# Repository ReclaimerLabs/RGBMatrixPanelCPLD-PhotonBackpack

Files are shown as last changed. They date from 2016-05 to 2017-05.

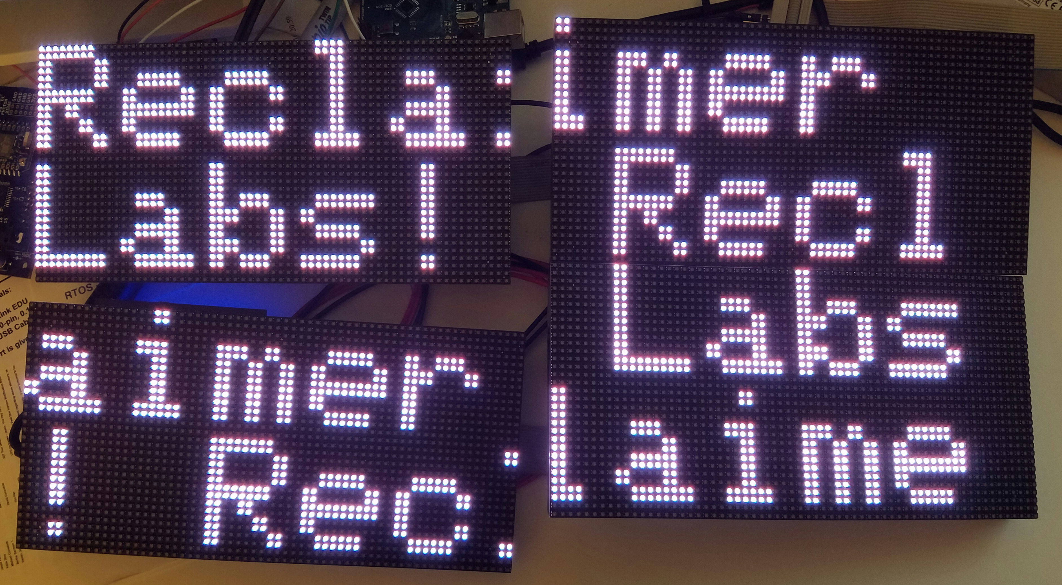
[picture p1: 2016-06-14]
documentation/panel_prototype.jpg

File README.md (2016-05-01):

Copyright (c) 2016 Jason Cerundolo

Permission is hereby granted, free of charge, to any person obtaining a copy
of this software and associated documentation files (the "Software"), to deal
in the Software without restriction, including without limitation the rights
to use, copy, modify, merge, publish, distribute, sublicense, and/or sell
copies of the Software, and to permit persons to whom the Software is
furnished to do so, subject to the following conditions:

The above copyright notice and this permission notice shall be included in all
copies or substantial portions of the Software.

THE SOFTWARE IS PROVIDED "AS IS", WITHOUT WARRANTY OF ANY KIND, EXPRESS OR
IMPLIED, INCLUDING BUT NOT LIMITED TO THE WARRANTIES OF MERCHANTABILITY,
FITNESS FOR A PARTICULAR PURPOSE AND NONINFRINGEMENT. IN NO EVENT SHALL THE
AUTHORS OR COPYRIGHT HOLDERS BE LIABLE FOR ANY CLAIM, DAMAGES OR OTHER
LIABILITY, WHETHER IN AN ACTION OF CONTRACT, TORT OR OTHERWISE, ARISING FROM,
OUT OF OR IN CONNECTION WITH THE SOFTWARE OR THE USE OR OTHER DEALINGS IN THE
SOFTWARE.

RGB Matrix Panel CPLD Photon Backpack
==================

An interface board between a Particle Photon and an RGB Matrix Panel. 
A CPLD provides the interface between the two and handles protocol 
conversion. 

Pick up an RGB LED panel from Adafruit. 
https://www.adafruit.com/products/2026

Pick up a CPLD backpack from Reclaimer Labs. 
http://reclaimerlabs.com

Use with the matching Particle library. 
https://github.com/ReclaimerLabs/RGBmatrixpanelCPLD

This board allows the use of hardware timers and DMA to achieve low 
overhead transfers of information to the matrix panels. The CPLD on the 
backpack converts SPI data into the parallel format expected by 
the matrix panel. The only ongoing computation needed from the CPU 
is to set up the next DMA transfer and compute the time to display 
the next row of bit data. This take the CPU time needed from ~40% 
to <1% for two 32x32 panels. The limited factor is now RAM and 
transfer speed.

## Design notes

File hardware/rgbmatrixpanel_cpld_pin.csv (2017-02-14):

ispLEVER Classic 2.0.00.17.20.15 Fitter Report File
Project Name | rgbmatrixpanel_cpld
Project Path | D:\Projects\RGBMatrixPanelCPLD-PhotonBackpack\hardware
Project Fitted on | Sun Feb 05 16:48:18 2017
Pin | Pin_Type | Bank | GLB_Pad | Assigned | I/O_Type | Signal_Type | Signal_Name
1 | TDI | -
2 | I_O | 0 | A5
3 | I_O | 0 | A6
4 | I_O | 0 | A7
5 | GNDIO0 | -
6 | VCCIO0 | -
7 | I_O | 0 | A8
8 | I_O | 0 | A9
9 | I_O | 0 | A10
10 | TCK | -
11 | VCC | -
12 | GND | -
13 | I_O | 0 | A12
14 | I_O | 0 | A13
15 | I_O | 0 | A14
16 | I_O | 0 | A15 | * | LVCMOS18 | Output | clk_out
17 | INCLK2 | 1
18 | I_O | 1 | B0 | * | LVCMOS18 | Output | latch_out
19 | I_O | 1 | B1 | * | LVCMOS18 | Output | row_2_
20 | I_O | 1 | B2 | * | LVCMOS18 | Output | row_3_
21 | I_O | 1 | B3 | * | LVCMOS18 | Output | row_0_
22 | I_O | 1 | B4 | * | LVCMOS18 | Output | row_1_
23 | TMS | -
24 | I_O | 1 | B5 | * | LVCMOS18 | Output | rgbs_0_
25 | I_O | 1 | B6 | * | LVCMOS18 | Output | rgbs_2_
26 | I_O | 1 | B7 | * | LVCMOS18 | Output | rgbs_1_
27 | GNDIO1 | -
28 | VCCIO1 | -
29 | I_O | 1 | B8 | * | LVCMOS18 | Output | rgbs_3_
30 | I_O | 1 | B9 | * | LVCMOS18 | Output | rgbs_5_
31 | I_O | 1 | B10 | * | LVCMOS18 | Output | rgbs_4_
32 | TDO | -
33 | VCC | -
34 | GND | -
35 | I_O | 1 | B12
36 | I_O | 1 | B13 | * | LVCMOS18 | Input | reset
37 | I_O | 1 | B14 | * | LVCMOS18 | Input | clk
38 | I_O/OE | 1 | B15
39 | INCLK0 | 0 |  | * | LVCMOS18 | Input | si
40 | I_O/OE | 0 | A0 |  | LVCMOS18 | Output | rgbs_7_
41 | I_O | 0 | A1
42 | I_O | 0 | A2 |  | LVCMOS18 | Output | rgbs_6_
43 | I_O | 0 | A3
44 | I_O | 0 | A4

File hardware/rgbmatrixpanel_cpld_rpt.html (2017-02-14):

 ispLEVER Classic 2.0.00.17.20.15 Fitter Report File

Copyright(C), 1992-2012, Lattice Semiconductor Corporation

All Rights Reserved

The Basic/Detailed Report Format can be selected in the dialog box
Tools->Fitter Report File Format...

Project_Summary

Project Name         :  rgbmatrixpanel_cpld
Project Path         :  D:\Projects\RGBMatrixPanelCPLD-PhotonBackpack\hardware
Project Fitted on    :  Sun Feb 05 16:48:18 2017

Device               :  M4032_30
Package              :  44
GLB Input Mux Size   :  6
Available Blocks     :  2
Speed                :  -7.5
Part Number          :  LC4032V-75T44C
Source Format        :  Pure_Verilog_HDL

Project 'rgbmatrixpanel_cpld' Fit Successfully!

Compilation_Times

Prefit Time                     0 secs
Load Design Time                0.01 secs
Partition Time                  0.00 secs
Place Time                      0.00 secs
Route Time                      0.00 secs
Total Fit Time                  00:00:01

Design_Summary

Total Input Pins                3
Total Logic Functions           20
  Total Output Pins             14
  Total Bidir I/O Pins          0
  Total Buried Nodes            6
Total Flip-Flops                19
  Total D Flip-Flops            19
  Total T Flip-Flops            0
  Total Latches                 0
Total Product Terms             74

Total Reserved Pins             0
Total Locked Pins               15
Total Locked Nodes              0

Total Unique Output Enables     0
Total Unique Clocks             2
Total Unique Clock Enables      3
Total Unique Resets             1
Total Unique Presets            1

Fmax Logic Levels               2

Device_Resource_Summary

                                 Device
                                 Total    Used   Not Used   Utilization
-----------------------------------------------------------------------
Dedicated Pins
  Clock/Input Pins                  2        1      1    -->    50
  I/O / Enable Pins                 2        1      1    -->    50
I/O Pins                           28       15     13    -->    53
Logic Functions                    32       20     12    -->    62
  Input Registers                  30        0     30    -->     0

GLB Inputs                         72       27     45    -->    37
Logical Product Terms             160       43    117    -->    26
Occupied GLBs                       2        2      0    -->   100
Macrocells                         32       20     12    -->    62

Control Product Terms:
  GLB Clock/Clock Enables           2        2      0    -->   100
  GLB Reset/Presets                 2        0      2    -->     0
  Macrocell Clocks                 32        7     25    -->    21
  Macrocell Clock Enables          32        6     26    -->    18
  Macrocell Enables                32        0     32    -->     0
  Macrocell Resets                 32        0     32    -->     0
  Macrocell Presets                32        0     32    -->     0

Global Routing Pool                64       21     43    -->    32
  GRP from IFB                     ..        3     ..    -->    ..
    (from input signals)           ..        3     ..    -->    ..
    (from output signals)          ..        0     ..    -->    ..
    (from bidir signals)           ..        0     ..    -->    ..
  GRP from MFB                     ..       18     ..    -->    ..
----------------------------------------------------------------------

<Note> 1 : The available PT is the product term that has not been used.
<Note> 2 : IFB is I/O feedback.
<Note> 3 : MFB is macrocell feedback.

GLB_Resource_Summary

                                                                                     # of PT
               ---  Fanin  ---    I/O    Input  Macrocells       Macrocells   Logic  clusters
             Unique Shared Total  Pins    Regs Used Inaccessible  available    PTs   used
-------------------------------------------------------------------------------------------
Maximum
  GLB                      36      *(1)     8   --     --             16       80       16
-------------------------------------------------------------------------------------------
  GLB    A      4     6    10      2/15     0    9      0              7       17        9
  GLB    B      8     9    17     13/15     0   11      0              5       26       11
-------------------------------------------------------------------------------------------
TOTALS:        12    15    27     15/30     0   20      0             12       43       20

<Note> 1 : For ispMACH 4000 devices, the number of IOs depends on the GLB.
<Note> 2 : Four rightmost columns above reflect last status of the placement process.

GLB_Control_Summary

           Shared Shared | Mcell  Mcell  Mcell  Mcell  Mcell 
           Clk/CE Rst/Pr | Clock  CE     Enable Reset  Preset
------------------------------------------------------------------------------
Maximum
  GLB        1      1        16     16     16     16     16  
==============================================================================
  GLB    A   1      0         2      2      0      0      0
  GLB    B   1      0         5      4      0      0      0
------------------------------------------------------------------------------

<Note> 1 : For ispMACH 4000 devices, the number of output enables depends on the GLB.

Optimizer_and_Fitter_Options

Pin Assignment :                       Yes
Group Assignment :                     No
Pin Reservation :                      No

@Ignore_Project_Constraints :
  Pin Assignments :                    No
      Keep Block Assignment            --
      Keep Segment Assignment          --
  Group Assignments :                  No
  Macrocell Assignment :               No
      Keep Block Assignment            --
      Keep Segment Assignment          --

@Backannotate_Project_Constraints
  Pin Assignments :                    No
  Pin And Block Assignments :          No
  Pin, Macrocell and Block :           No

@Timing_Constraints :                  No

@Global_Project_Optimization :
  Balanced Partitioning :              Yes
  Spread Placement :                   Yes

  Note :
    Pack Design :
       Balanced Partitioning = No
       Spread Placement      = No
    Spread Design :
       Balanced Partitioning = Yes
       Spread Placement      = Yes

@Logic_Synthesis :
  Logic Reduction :                    Yes
  Node Collapsing :                    FMAX
  Fmax_Logic_Level :                   1
  D/T Synthesis :                      Yes
  XOR Synthesis :                      Yes
  Max. P-Term for Collapsing :         16
  Max. P-Term for Splitting :          80
  Max Symbols :                        24

@Utilization_options
  Max. % of Macrocells used :          100
@Usercode                               (HEX)
@IO_Types                              Default = LVCMOS18 (2)
@Output_Slew_Rate                      Default = FAST (2)
@Power                                 Default = HIGH (2)
@Pull                                  Default = PULLUP_UP (2)
@Fast_Bypass                           Default = None (2)
@ORP_Bypass                            Default = None
@Input_Registers                       Default = None (2)
@Register_Powerup                      Default = None

Device Options:
<Note> 1 : Reserved unused I/Os can be independently driven to Low or High, and does not
           follow the drive level set for the Global Configure Unused I/O Option.
<Note> 2 : For user-specified constraints on individual signals, refer to the Output,
           Bidir and Buried Signal Lists.

Pinout_Listing

      | Pin   | Bank |GLB |Assigned|                 | Signal|
Pin No| Type  |Number|Pad |Pin     |     I/O Type    | Type  | Signal name
----------------------------------------------------------------------------------
1     | TDI   |   -  |    |        |                 |       |
2     |  I_O  |   0  | A5 |        |                 |       |
3     |  I_O  |   0  | A6 |        |                 |       |
4     |  I_O  |   0  | A7 |        |                 |       |
5     |GNDIO0 |   -  |    |        |                 |       |
6     |VCCIO0 |   -  |    |        |                 |       |
7     |  I_O  |   0  | A8 |        |                 |       |
8     |  I_O  |   0  | A9 |        |                 |       |
9     |  I_O  |   0  | A10|        |                 |       |
10    | TCK   |   -  |    |        |                 |       |
11    | VCC   |   -  |    |        |                 |       |
12    | GND   |   -  |    |        |                 |       |
13    |  I_O  |   0  | A12|        |                 |       |
14    |  I_O  |   0  | A13|        |                 |       |
15    |  I_O  |   0  | A14|        |                 |       |
16    |  I_O  |   0  | A15|    *   |LVCMOS18         | Output|clk_out
17    |INCLK2 |   1  |    |        |                 |       |
18    |  I_O  |   1  | B0 |    *   |LVCMOS18         | Output|latch_out
19    |  I_O  |   1  | B1 |    *   |LVCMOS18         | Output|row_2_
20    |  I_O  |   1  | B2 |    *   |LVCMOS18         | Output|row_3_
21    |  I_O  |   1  | B3 |    *   |LVCMOS18         | Output|row_0_
22    |  I_O  |   1  | B4 |    *   |LVCMOS18         | Output|row_1_
23    | TMS   |   -  |    |        |                 |       |
24    |  I_O  |   1  | B5 |    *   |LVCMOS18         | Output|rgbs_0_
25    |  I_O  |   1  | B6 |    *   |LVCMOS18         | Output|rgbs_2_
26    |  I_O  |   1  | B7 |    *   |LVCMOS18         | Output|rgbs_1_
27    |GNDIO1 |   -  |    |        |                 |       |
28    |VCCIO1 |   -  |    |        |                 |       |
29    |  I_O  |   1  | B8 |    *   |LVCMOS18         | Output|rgbs_3_
30    |  I_O  |   1  | B9 |    *   |LVCMOS18         | Output|rgbs_5_
31    |  I_O  |   1  | B10|    *   |LVCMOS18         | Output|rgbs_4_
32    | TDO   |   -  |    |        |                 |       |
33    | VCC   |   -  |    |        |                 |       |
34    | GND   |   -  |    |        |                 |       |
35    |  I_O  |   1  | B12|        |                 |       |
36    |  I_O  |   1  | B13|    *   |LVCMOS18         | Input |reset
37    |  I_O  |   1  | B14|    *   |LVCMOS18         | Input |clk
38    | I_O/OE|   1  | B15|        |                 |       |
39    |INCLK0 |   0  |    |    *   |LVCMOS18         | Input |si
40    | I_O/OE|   0  | A0 |        |LVCMOS18         | Output|rgbs_7_
41    |  I_O  |   0  | A1 |        |                 |       |
42    |  I_O  |   0  | A2 |        |LVCMOS18         | Output|rgbs_6_
43    |  I_O  |   0  | A3 |        |                 |       |
44    |  I_O  |   0  | A4 |        |                 |       |
----------------------------------------------------------------------------------

<Note> GLB Pad : This notation refers to the GLB I/O pad number in the device.
<Note> Assigned Pin : user or dedicated input assignment (E.g. Clock pins).
<Note> Pin Type : 
          ClkIn : Dedicated input or clock pin 
           CLK  : Dedicated clock pin
           I_O  : Input/Output pin
           INP  : Dedicated input pin
           JTAG : JTAG Control and test pin
           NC   : No connected

Input_Signal_List

                Input
         Pin    Fanout
 Pin GLB Type         Pullup Signal
-----------------------------------
  37   B  I/O   2 AB      Up clk
  36   B  I/O   2 AB      Up reset
  39  -- INCLK  1 -B      Up si
-----------------------------------

Output_Signal_List

          I         C      P R P       O Output
          N         L Mc   R E U C O F B Fanout
 Pin GLB  P LL PTs  S Type E S P E E P P       Slew Pullup Signal
--------------------------------------------------------------------
  16   A  5  1   2  1 DFF  *   S           --  Fast     Up clk_out
  18   B  6  1   2  1 DFF    * R           --  Fast     Up latch_out
  24   B  3  -   1  1 DFF    * R         1 -B  Fast     Up rgbs_0_
  26   B  3  1   1  1 DFF    * R         1 -B  Fast     Up rgbs_1_
  25   B  3  1   1  1 DFF    * R         1 -B  Fast     Up rgbs_2_
  29   B  3  1   1  1 DFF    * R         1 -B  Fast     Up rgbs_3_
  31   B  3  1   1  1 DFF    * R         1 -B  Fast     Up rgbs_4_
  30   B  3  1   1  1 DFF    * R         1 A-  Fast     Up rgbs_5_
  42   A  3  1   1  1 DFF    * R         1 A-  Fast     Up rgbs_6_
  40   A  3  1   1  1 DFF    * R         1 A-  Fast     Up rgbs_7_
  21   B  7  1   3  1 DFF  *   S *       1 -B  Fast     Up row_0_
  22   B  8  1   4  1 DFF  *   S *       1 -B  Fast     Up row_1_
  19   B  9  1   5  1 DFF  *   S *       1 -B  Fast     Up row_2_
  20   B 10  1   6  2 DFF  *   S *       1 -B  Fast     Up row_3_
--------------------------------------------------------------------

<Note> CLS = Number of clusters used
       INP = Number of input signals
       PTs = Number of product terms
        LL = Number of logic levels
       PRE = Has preset equation
       RES = Has reset equation
       PUP = Power-Up initial state: R=Reset, S=Set
        CE = Has clock enable equation
        OE = Has output enable equation
        FP = Fast path used
       OBP = ORP bypass used

Bidir_Signal_List

          I         C      P R P       O Bidir
          N         L Mc   R E U C O F B Fanout
 Pin GLB  P LL PTs  S Type E S P E E P P       Slew Pullup Signal
-----------------------------------------------------------------
-----------------------------------------------------------------

<Note> CLS = Number of clusters used
       INP = Number of input signals
       PTs = Number of product terms
        LL = Number of logic levels
       PRE = Has preset equation
       RES = Has reset equation
       PUP = Power-Up initial state: R=Reset, S=Set
        CE = Has clock enable equation
        OE = Has output enable equation
        FP = Fast path used
       OBP = ORP bypass used

Buried_Signal_List

        I         C      P R P       Node
        N         L Mc   R E U C I F Fanout
Mc GLB  P LL PTs  S Type E S P E R P       Signal
--------------------------------------------------------------
12   A  3  1   1  1 DFF    * R       2 AB  counter_0_
 4   A  4  1   2  1 DFF    * R       2 AB  counter_1_
 2   A  5  1   3  1 DFF    * R       2 AB  counter_2_
 1   A  4  1   3  1 DFF  *   S *     2 AB  inst_latch_needed
 5   A  5  -   2  1 COM              1 A-  inst_latch_needed_0
 3   A  6  1   2  1 DFF  *   S *     1 -B  inst_row_inc_needed
--------------------------------------------------------------

<Note> CLS = Number of clusters used
       INP = Number of input signals
       PTs = Number of product terms
        LL = Number of logic levels
       PRE = Has preset equation
       RES = Has reset equation
       PUP = Power-Up initial state: R=Reset, S=Set
        CE = Has clock enable equation
        OE = Has output enable equation
        IR = Input register
        FP = Fast path used
       OBP = ORP bypass used

PostFit_Equations

clk_out.D = !counter_0_.Q & !counter_1_.Q & !counter_2_.Q ; (1 pterm, 3 signals)
clk_out.C = !clk ; (1 pterm, 1 signal)
clk_out.AP = !reset ; (1 pterm, 1 signal)

counter_0_.D = !counter_0_.Q ; (1 pterm, 1 signal)
counter_0_.C = clk ; (1 pterm, 1 signal)
counter_0_.AR = !reset ; (1 pterm, 1 signal)

counter_1_.D = counter_0_.Q & !counter_1_.Q
    # !counter_0_.Q & counter_1_.Q ; (2 pterms, 2 signals)
counter_1_.C = clk ; (1 pterm, 1 signal)
counter_1_.AR = !reset ; (1 pterm, 1 signal)

counter_2_.D = counter_0_.Q & counter_1_.Q & !counter_2_.Q
    # !counter_1_.Q & counter_2_.Q
    # !counter_0_.Q & counter_2_.Q ; (3 pterms, 3 signals)
counter_2_.C = clk ; (1 pterm, 1 signal)
counter_2_.AR = !reset ; (1 pterm, 1 signal)

inst_latch_needed.D = !counter_1_.Q ; (1 pterm, 1 signal)
inst_latch_needed.C = !clk ; (1 pterm, 1 signal)
inst_latch_needed.CE = inst_latch_needed_0 ; (1 pterm, 1 signal)
inst_latch_needed.AP = !reset ; (1 pterm, 1 signal)

inst_latch_needed_0 = rgbs_6_.Q & !counter_0_.Q & !counter_1_.Q
       & !counter_2_.Q
    # !counter_0_.Q & counter_1_.Q & !counter_2_.Q & inst_latch_needed.Q ; (2 pterms, 5 signals)

inst_row_inc_needed.D = rgbs_7_.Q ; (1 pterm, 1 signal)
inst_row_inc_needed.C = clk ; (1 pterm, 1 signal)
inst_row_inc_needed.CE = !counter_0_.Q & !counter_1_.Q & !counter_2_.Q ; (1 pterm, 3 signals)
inst_row_inc_needed.AP = !reset ; (1 pterm, 1 signal)

latch_out.D = !counter_0_.Q & counter_1_.Q & !counter_2_.Q
       & inst_latch_needed.Q ; (1 pterm, 4 signals)
latch_out.C = !clk ; (1 pterm, 1 signal)
latch_out.AR = !reset ; (1 pterm, 1 signal)

rgbs_0_.D = si ; (1 pterm, 1 signal)
rgbs_0_.C = clk ; (1 pterm, 1 signal)
rgbs_0_.AR = !reset ; (1 pterm, 1 signal)

rgbs_1_.D = rgbs_0_.Q ; (1 pterm, 1 signal)
rgbs_1_.C = clk ; (1 pterm, 1 signal)
rgbs_1_.AR = !reset ; (1 pterm, 1 signal)

rgbs_2_.D = rgbs_1_.Q ; (1 pterm, 1 signal)
rgbs_2_.C = clk ; (1 pterm, 1 signal)
rgbs_2_.AR = !reset ; (1 pterm, 1 signal)

rgbs_3_.D = rgbs_2_.Q ; (1 pterm, 1 signal)
rgbs_3_.C = clk ; (1 pterm, 1 signal)
rgbs_3_.AR = !reset ; (1 pterm, 1 signal)

rgbs_4_.D = rgbs_3_.Q ; (1 pterm, 1 signal)
rgbs_4_.C = clk ; (1 pterm, 1 signal)
rgbs_4_.AR = !reset ; (1 pterm, 1 signal)

rgbs_5_.D = rgbs_4_.Q ; (1 pterm, 1 signal)
rgbs_5_.C = clk ; (1 pterm, 1 signal)
rgbs_5_.AR = !reset ; (1 pterm, 1 signal)

rgbs_6_.D = rgbs_5_.Q ; (1 pterm, 1 signal)
rgbs_6_.C = clk ; (1 pterm, 1 signal)
rgbs_6_.AR = !reset ; (1 pterm, 1 signal)

rgbs_7_.D = rgbs_6_.Q ; (1 pterm, 1 signal)
rgbs_7_.C = clk ; (1 pterm, 1 signal)
rgbs_7_.AR = !reset ; (1 pterm, 1 signal)

row_0_.D = !row_0_.Q ; (1 pterm, 1 signal)
row_0_.C = !clk ; (1 pterm, 1 signal)
row_0_.CE = counter_0_.Q & !counter_1_.Q & !counter_2_.Q
       & inst_row_inc_needed.Q ; (1 pterm, 4 signals)
row_0_.AP = !reset ; (1 pterm, 1 signal)

row_1_.D = !row_1_.Q & row_0_.Q
    # row_1_.Q & !row_0_.Q ; (2 pterms, 2 signals)
row_1_.C = !clk ; (1 pterm, 1 signal)
row_1_.CE = counter_0_.Q & !counter_1_.Q & !counter_2_.Q
       & inst_row_inc_needed.Q ; (1 pterm, 4 signals)
row_1_.AP = !reset ; (1 pterm, 1 signal)

row_2_.D = !row_2_.Q & row_1_.Q & row_0_.Q
    # row_2_.Q & !row_1_.Q
    # row_2_.Q & !row_0_.Q ; (3 pterms, 3 signals)
row_2_.C = !clk ; (1 pterm, 1 signal)
row_2_.CE = counter_0_.Q & !counter_1_.Q & !counter_2_.Q
       & inst_row_inc_needed.Q ; (1 pterm, 4 signals)
row_2_.AP = !reset ; (1 pterm, 1 signal)

row_3_.D = !row_3_.Q & row_2_.Q & row_1_.Q & row_0_.Q
    # row_3_.Q & !row_2_.Q
    # row_3_.Q & !row_1_.Q
    # row_3_.Q & !row_0_.Q ; (4 pterms, 4 signals)
row_3_.C = !clk ; (1 pterm, 1 signal)
row_3_.CE = counter_0_.Q & !counter_1_.Q & !counter_2_.Q
       & inst_row_inc_needed.Q ; (1 pterm, 4 signals)
row_3_.AP = !reset ; (1 pterm, 1 signal)

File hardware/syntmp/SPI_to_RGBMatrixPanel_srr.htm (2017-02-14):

#Build: Synplify Pro I-2014.03LC , Build 063R, May 27 2014
#install: C:\ispLEVER_Classic2_0\synpbase
#OS: Windows 7 6.1
#Hostname: SPEEDY

#Implementation: hardware

$ Start of Compile
#Sun Feb 05 16:48:10 2017

Synopsys Verilog Compiler, version comp201403rcp1, Build 060R, built May 27 2014
@N: :  | Running in 64-bit mode 
Copyright (C) 1994-2014 Synopsys, Inc. This software and the associated documentation are proprietary to Synopsys, Inc. This software may only be used in accordance with the terms and conditions of a written license agreement with Synopsys, Inc.  All other use, reproduction, or distribution of this software is strictly prohibited.

@I::"C:\ispLEVER_Classic2_0\synpbase\lib\vlog\umr_capim.v"
@I::"C:\ispLEVER_Classic2_0\synpbase\lib\vlog\scemi_objects.v"
@I::"C:\ispLEVER_Classic2_0\synpbase\lib\vlog\scemi_pipes.svh"
@I::"C:\ispLEVER_Classic2_0\synpbase\lib\vlog\hypermods.v"
@I::"C:\ispLEVER_Classic2_0\ispcpld\..\cae_library\synthesis\verilog\mach.v"
@I::"D:\projects\rgbmatrixpanelcpld-photonbackpack\hardware\rgbmatrixpanel_cpld.h"
@I::"D:\projects\rgbmatrixpanelcpld-photonbackpack\hardware\spi_to_rgbmatrixpanel.v"
Verilog syntax check successful!

Compiler output is up to date.  No re-compile necessary

Selecting top level module SPI_to_RGBMatrixPanel
@N:CG364 : spi_to_rgbmatrixpanel.v(1) | Synthesizing module SPI_to_RGBMatrixPanel

@END

At c_ver Exit (Real Time elapsed 0h:00m:00s; CPU Time elapsed 0h:00m:00s; Memory used current: 67MB peak: 68MB)

Process took 0h:00m:01s realtime, 0h:00m:01s cputime
# Sun Feb 05 16:48:11 2017

###########################################################]
Synopsys Netlist Linker, version comp201403rcp1, Build 060R, built May 27 2014
@N: :  | Running in 64-bit mode 

Linker output is up to date. No re-linking necessary

At syn_nfilter Exit (Real Time elapsed 0h:00m:00s; CPU Time elapsed 0h:00m:00s; Memory used current: 67MB peak: 68MB)

Process took 0h:00m:01s realtime, 0h:00m:01s cputime
# Sun Feb 05 16:48:12 2017

###########################################################]
Map & Optimize Report

Synopsys CPLD Technology Mapper, Version maplat, Build 923R, Built May  6 2014
Copyright (C) 1994-2013, Synopsys, Inc. This software and the associated documentation are proprietary to Synopsys, Inc. This software may only be used in accordance with the terms and conditions of a written license agreement with Synopsys, Inc.  All other use or distribution of the software is strictly prohibited.
Product Version I-2014.03LC 
@N:MF248 :  | Running in 64-bit mode. 
@N: : spi_to_rgbmatrixpanel.v(23) | Found counter in view:work.SPI_to_RGBMatrixPanel(verilog) inst row[3:0]
@N: : spi_to_rgbmatrixpanel.v(58) | Found counter in view:work.SPI_to_RGBMatrixPanel(verilog) inst counter[2:0]
---------------------------------------
Resource Usage Report

Simple gate primitives:
DFFRH           12 uses
DFFCSH          6 uses
DFFSH           1 use
IBUF            3 uses
OBUF            14 uses
AND2            13 uses
INV             9 uses
XOR2            5 uses

@N:FC100 :  | Timing Report not generated for this device, please use place and route tools for timing analysis. 
I-2014.03LC 
Mapper successful!

At Mapper Exit (Real Time elapsed 0h:00m:00s; CPU Time elapsed 0h:00m:00s; Memory used current: 37MB peak: 102MB)

Process took 0h:00m:01s realtime, 0h:00m:01s cputime
# Sun Feb 05 16:48:12 2017

###########################################################]

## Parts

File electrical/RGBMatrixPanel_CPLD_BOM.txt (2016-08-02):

Reference	Quantity	 Value	 Footprint	 Datasheet	 DNP	 Manufacturer	 Manufacturer Part Number	 Supplier 1	 Supplier 1 Part Number
C3 C4	2	100uF	Capacitors_SMD:c_elec_6.3x5.7			Nichicon	UWX1A101MCL1GB	Digikey	493-2096-1-ND
C5	1	10uF	Capacitors_SMD:C_0805			Yageo	CC0805KKX5R6BB106	Digikey	311-1460-1-ND
C6 C7 C8 C9 C10	5	0.1uF	Capacitors_SMD:C_0603			Yageo	CC0603KRX7R7BB104	Digikey	311-1088-1-ND
D1	1	D_Schottky	Reclaimer_Labs:SMini2-F5-B			Panasonic	DB2J20900L	Digikey	DB2J20900LCT-ND
J1	1	BARREL_JACK	Reclaimer_Labs:BARREL_JACK_MPD_EJ508A			CUI	PJ-202AH	Digikey	CP-202AH-ND
J2 J3 J4 J5	4	CONN_01X01	3547			Keystone	3547	Digikey	36-3547-ND
J6	1	CONN_01X06	Socket_Strips:Socket_Strip_Straight_1x06		DNP				
J7	1	CONN_02X08	Reclaimer_Labs:HEADER_THRU_02x08_POL			Sullins	SFH11-PBPC-D08-ST-BK	Digikey	S9196-ND
J8	1	CONN_01X06	Socket_Strips:Socket_Strip_Straight_1x06		DNP				
Q1	1	Photo_Trans	Reclaimer_Labs:Photo_Trans_0805			Rohm	RPM-075PTT86	Digikey	511-1356-1-ND
R1	1	100R	Resistors_SMD:R_0603			Samsung	RC1608F101CS	Digikey	1276-3482-1-ND
R2	1	10k	Resistors_SMD:R_0603			Samsung	RC1608F103CS	Digikey	1276-3485-1-ND
U1	1	PHOTON	Reclaimer_Labs:PHOTON		DNP				
U2	1	LC4032V-44TQFP	Reclaimer_Labs:QFP_44			Lattice	LC4032V-75TN44C	Digikey	220-1034-ND
U3	1	TSOP75238TT	Reclaimer_Labs:TSOP75238TT			Vishay	TSOP75238TR	Digikey	TSOP75238CT-ND

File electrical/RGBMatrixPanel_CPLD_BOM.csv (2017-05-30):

Reference | Value | Footprint | DNP | Manufacturer | Manufacturer Part Number | Supplier 1 | Supplier 1 Part Number | MacroFab Part Number | Column1
C1 | 10uF | Capacitors_SMD:C_1206 |  | Samsung | CL31A106MBHNNNE
C10 | 0.1uF | Capacitors_SMD:C_0603 |  | Yageo | CC0603KRX7R9BB103 | Digikey | 311-1085-1-ND
C11 | 1000pF | Capacitors_SMD:C_0603 |  |  |  |  |  | MF-CAP-0603-1nF
C12 | 1uF | Capacitors_SMD:C_0603 |  |  |  |  |  | MF-CAP-0603-1uF
C13 | 0.1uF | Capacitors_SMD:C_0603 |  |  |  |  |  | MF-CAP-0603-0.1uF
C14 | 100uF | Capacitors_SMD:C_1206 |  | Murata | GRM31CR60J107ME39L
C15 | 100uF | Capacitors_SMD:C_1206 |  | Murata | GRM31CR60J107ME39L
C16 | 4700pF | Capacitors_SMD:C_0603 |  |  |  |  |  | MF-CAP-0603-4.7nF
C17 | 1000pF | Capacitors_SMD:C_0603 |  |  |  |  |  | MF-CAP-0603-1nF
C18 | 0.1uF | Capacitors_SMD:C_0603 |  |  |  |  |  | MF-CAP-0603-0.1uF
C2 | 10uF | Capacitors_SMD:C_1206 |  | Samsung | CL31A106MBHNNNE
C3 | 10uF | Capacitors_SMD:C_1206 |  | Samsung | CL31A106MBHNNNE
C4 | 0.1uF | Capacitors_SMD:C_0603 |  |  |  |  |  | MF-CAP-0603-0.1uF
C5 | DNP | Capacitors_SMD:C_0805 |  |  |  |  |  | MF-CAP-0805-0.1uF
C6 | 0.1uF | Capacitors_SMD:C_0603 |  | Yageo | CC0603KRX7R7BB104 | Digikey | 311-1088-1-ND
C7 | 0.1uF | Capacitors_SMD:C_0603 |  | Yageo | CC0603KRX7R7BB104 | Digikey | 311-1088-1-ND
C8 | 0.1uF | Capacitors_SMD:C_0603 |  | Yageo | CC0603KRX7R7BB104 | Digikey | 311-1088-1-ND
C9 | 0.1uF | Capacitors_SMD:C_0603 |  | Yageo | CC0603KRX7R9BB103 | Digikey | 311-1085-1-ND
J1 | BARREL_JACK | Reclaimer_Labs:BARREL_JACK_PJ_202AH_Slots |  | CUI | PJ-202AH | Digikey | CP-202AH-ND
J2 | CONN_01X01 | Reclaimer_Labs:3547 |  | Keystone | 3547 | Digikey | 36-3547-ND
J3 | CONN_01X01 | Reclaimer_Labs:3547 |  | Keystone | 3547 | Digikey | 36-3547-ND
J4 | CONN_01X01 | Reclaimer_Labs:3547 |  | Keystone | 3547 | Digikey | 36-3547-ND
J5 | CONN_01X01 | Reclaimer_Labs:3547 |  | Keystone | 3547 | Digikey | 36-3547-ND
J6 | CONN_01X06 | Socket_Strips:Socket_Strip_Straight_1x06
J7 | CONN_02X08 | Reclaimer_Labs:HEADER_THRU_02x08_POL |  | Sullins | SFH11-PBPC-D08-ST-BK | Digikey | S9196-ND
J8 | CONN_01X06 | Socket_Strips:Socket_Strip_Straight_1x06
J9 | CONN_01X03 | Socket_Strips:Socket_Strip_Straight_1x03
L1 | 1.5uH | Reclaimer_Labs:SRR1270 |  | Bourns | SRP1270-1R5M
Q1 | Photo_Trans | Reclaimer_Labs:Photo_Trans_0805 |  | Rohm | RPM-075PTT86 | Digikey | 511-1356-1-ND
R1 | 100R | Capacitors_SMD:C_0603 |  | Samsung | RC1608F101CS | Digikey | 1276-3482-1-ND
R10 | 100k | Capacitors_SMD:C_0603 |  |  |  |  |  | MF-RES-0603-100K
R11 | 0R | Capacitors_SMD:C_0603 |  |  |  |  |  | MF-RES-0603-0
R12 | 100k | Capacitors_SMD:C_0603 |  |  |  |  |  | MF-RES-0603-100K
R13 | 1R | Capacitors_SMD:C_0603 |  | Panasonic | ERJ-3RQF1R0V
R14 | 10k | Capacitors_SMD:C_0603 |  |  |  |  |  | MF-RES-0603-10K
R2 | 10k | Capacitors_SMD:C_0603 |  | Samsung | RC1608F103CS | Digikey | 1276-3485-1-ND
R3 | 470k | Capacitors_SMD:C_0603 |  |  |  |  |  | MF-RES-0603-470K
R4 | 10k | Capacitors_SMD:C_0603 |  |  |  |  |  | MF-RES-0603-10K
R5 | 73k2 | Capacitors_SMD:C_0603 |  | Yageo | RC0603FR-0773K2L
R6 | 10k | Capacitors_SMD:C_0603 |  |  |  |  |  | MF-RES-0603-10K
R7 | 45k3 | Capacitors_SMD:C_0603 |  | Panasonic | ERJ-3EKF4532V
R8 | 866k | Capacitors_SMD:C_0603 |  | Panasonic | ERJ-3EKF8663V
R9 | 1k | Capacitors_SMD:C_0603 |  |  |  |  |  | MF-RES-0603-1K
U1 | PHOTON | Reclaimer_Labs:PHOTON | DNP
U2 | LC4032V-44TQFP | Reclaimer_Labs:QFP_44 |  | Lattice | LC4032V-75TN44C | Digikey | 220-1034-ND
U3 | TPS53219A | Reclaimer_Labs:PVQFN-16-EP |  | TI | 296-36800-1-ND
U4 | CSD87351Q5D | Reclaimer_Labs:CSD87351Q5D |  | TI | CSD87351Q5D
X1 | MTHOLE | Reclaimer_Labs:MountingHole_3.5mm_Pad_Via
X2 | MTHOLE | Reclaimer_Labs:MountingHole_3.5mm_Pad_Via
X3 | MTHOLE | Reclaimer_Labs:MountingHole_3.5mm_Pad_Via

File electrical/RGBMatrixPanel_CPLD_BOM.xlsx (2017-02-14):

Reference | Value | Footprint | Datasheet | DNP | Manufacturer | Manufacturer Part Number | Supplier 1 | Supplier 1 Part Number | MacroFab Part Number
C1 | 4.7uF | Capacitors_SMD:C_1206 |  |  | Murata | GRM31CR71H475KA12L
C10 | 0.1uF | Capacitors_SMD:C_0603 |  |  | Yageo | CC0603KRX7R9BB103 | Digikey | 311-1085-1-ND
C11 | 0.47uF | Capacitors_SMD:C_0805 |  |  | Taiyo | EMK212B7474KD-T
C12 | 1.0uF | Capacitors_SMD:C_0603 |  |  |  |  |  |  | MF-CAP-0603-1uF
C13 | 390pF | Capacitors_SMD:C_0603 |  |  | Samsung | CL10B391KC8WPNC
C14 | 100uF | Capacitors_SMD:C_1206 |  |  | Murata | GRM31CR60J107ME39L
C15 | DNP | Capacitors_SMD:C_1206 |  |  | Murata | GRM31CR60J107ME39L
C2 | 4.7uF | Capacitors_SMD:C_1206 |  |  | Murata | GRM31CR71H475KA12L
C3 | 4.7uF | Capacitors_SMD:C_1206 |  |  | Murata | GRM31CR71H475KA12L
C4 | 0.1uF | Capacitors_SMD:C_0805 |  |  |  |  |  |  | MF-CAP-0805-0.1uF
C5 | 0.01uF | Capacitors_SMD:C_0603 |  |  |  |  |  |  | MF-CAP-0603-0.01uF
C6 | 0.1uF | Capacitors_SMD:C_0603 |  |  | Yageo | CC0603KRX7R7BB104 | Digikey | 311-1088-1-ND
C7 | 0.1uF | Capacitors_SMD:C_0603 |  |  | Yageo | CC0603KRX7R7BB104 | Digikey | 311-1088-1-ND
C8 | 0.1uF | Capacitors_SMD:C_0603 |  |  | Yageo | CC0603KRX7R7BB104 | Digikey | 311-1088-1-ND
C9 | 0.1uF | Capacitors_SMD:C_0603 |  |  | Yageo | CC0603KRX7R9BB103 | Digikey | 311-1085-1-ND
J1 | BARREL_JACK | Reclaimer_Labs:BARREL_JACK_PJ_202AH_Slots |  |  | CUI | PJ-202AH | Digikey | CP-202AH-ND
J2 | CONN_01X01 | Reclaimer_Labs:3547 |  |  | Keystone | 3547 | Digikey | 36-3547-ND
J3 | CONN_01X01 | Reclaimer_Labs:3547 |  |  | Keystone | 3547 | Digikey | 36-3547-ND
J4 | CONN_01X01 | Reclaimer_Labs:3547 |  |  | Keystone | 3547 | Digikey | 36-3547-ND
J5 | CONN_01X01 | Reclaimer_Labs:3547 |  |  | Keystone | 3547 | Digikey | 36-3547-ND
J6 | CONN_01X06 | Socket_Strips:Socket_Strip_Straight_1x06
J7 | CONN_02X08 | Reclaimer_Labs:HEADER_THRU_02x08_POL |  |  | Sullins | SFH11-PBPC-D08-ST-BK | Digikey | S9196-ND
J8 | CONN_01X06 | Socket_Strips:Socket_Strip_Straight_1x06
J9 | CONN_01X03 | Socket_Strips:Socket_Strip_Straight_1x03
L1 | 2.2uH | Reclaimer_Labs:SRR1270 |  |  | Bourns | SRP1270-2R2M
Q1 | Photo_Trans | Reclaimer_Labs:Photo_Trans_0805 |  |  | Rohm | RPM-075PTT86 | Digikey | 511-1356-1-ND
Q2 | CSD17307Q5A | Reclaimer_Labs:MOSFET_Q5A |  |  | TI | CSD17307Q5A
Q3 | CSD18531Q5A | Reclaimer_Labs:MOSFET_Q5A |  |  | TI | CSD18531Q5A
R1 | 100R | Capacitors_SMD:C_0603 |  |  | Samsung | RC1608F101CS | Digikey | 1276-3482-1-ND
R2 | 10k | Capacitors_SMD:C_0603 |  |  | Samsung | RC1608F103CS | Digikey | 1276-3485-1-ND
R3 | 73k2 | Capacitors_SMD:C_0603 |  |  | Yageo | RC0603FR-0773K2L
R4 | 1k69 | Capacitors_SMD:C_0603 |  |  |  |  |  |  | MF-RES-0603-1.69K
R5 | 73k2 | Capacitors_SMD:C_0603 |  |  | Yageo | RC0603FR-0773K2L
R6 | 10k | Capacitors_SMD:C_0603 |  |  |  |  |  |  | MF-RES-0603-10K
U1 | PHOTON | Reclaimer_Labs:PHOTON |  | DNP
U2 | LC4032V-44TQFP | Reclaimer_Labs:QFP_44 |  |  | Lattice | LC4032V-75TN44C | Digikey | 220-1034-ND
U3 | LM3150 | Reclaimer_Labs:TSSOP-14-0.65mm-EP |  |  | TI | LM3150MHX/NOPB
X1 | MTHOLE | Reclaimer_Labs:MountingHole_3.5mm_Pad_Via
X2 | MTHOLE | Reclaimer_Labs:MountingHole_3.5mm_Pad_Via
X3 | MTHOLE | Reclaimer_Labs:MountingHole_3.5mm_Pad_Via

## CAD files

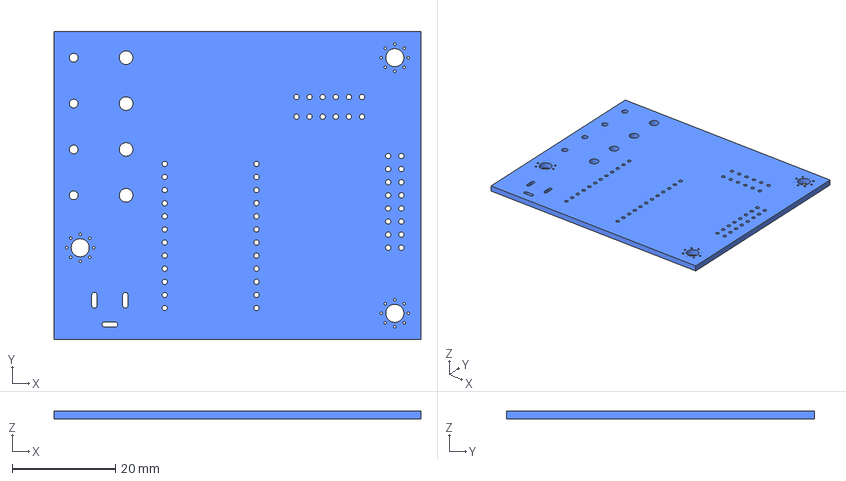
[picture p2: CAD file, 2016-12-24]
electrical/RGBMatrixPanel_CPLD.step
71.1 x 59.7 x 1.60 mm

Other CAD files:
electrical/RGBMatrixPanel_CPLD.FCStd

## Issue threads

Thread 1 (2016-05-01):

USB port on Photon interference

ReclaimerLabs, 2016-05-01:
The placement of the power header blocks the use of the USB port on the Photon with it soldered down. Even without the header, the USB port is placed too far from the board edge such that the cable overmold interferes with the PCB.

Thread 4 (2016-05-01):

Components too tall

ReclaimerLabs, 2016-05-01:
The height of the components would interfere with proposed methods of mounting the RGB matrix panels on a wall. Additionally, the location of the DC barrel connector is awkward.

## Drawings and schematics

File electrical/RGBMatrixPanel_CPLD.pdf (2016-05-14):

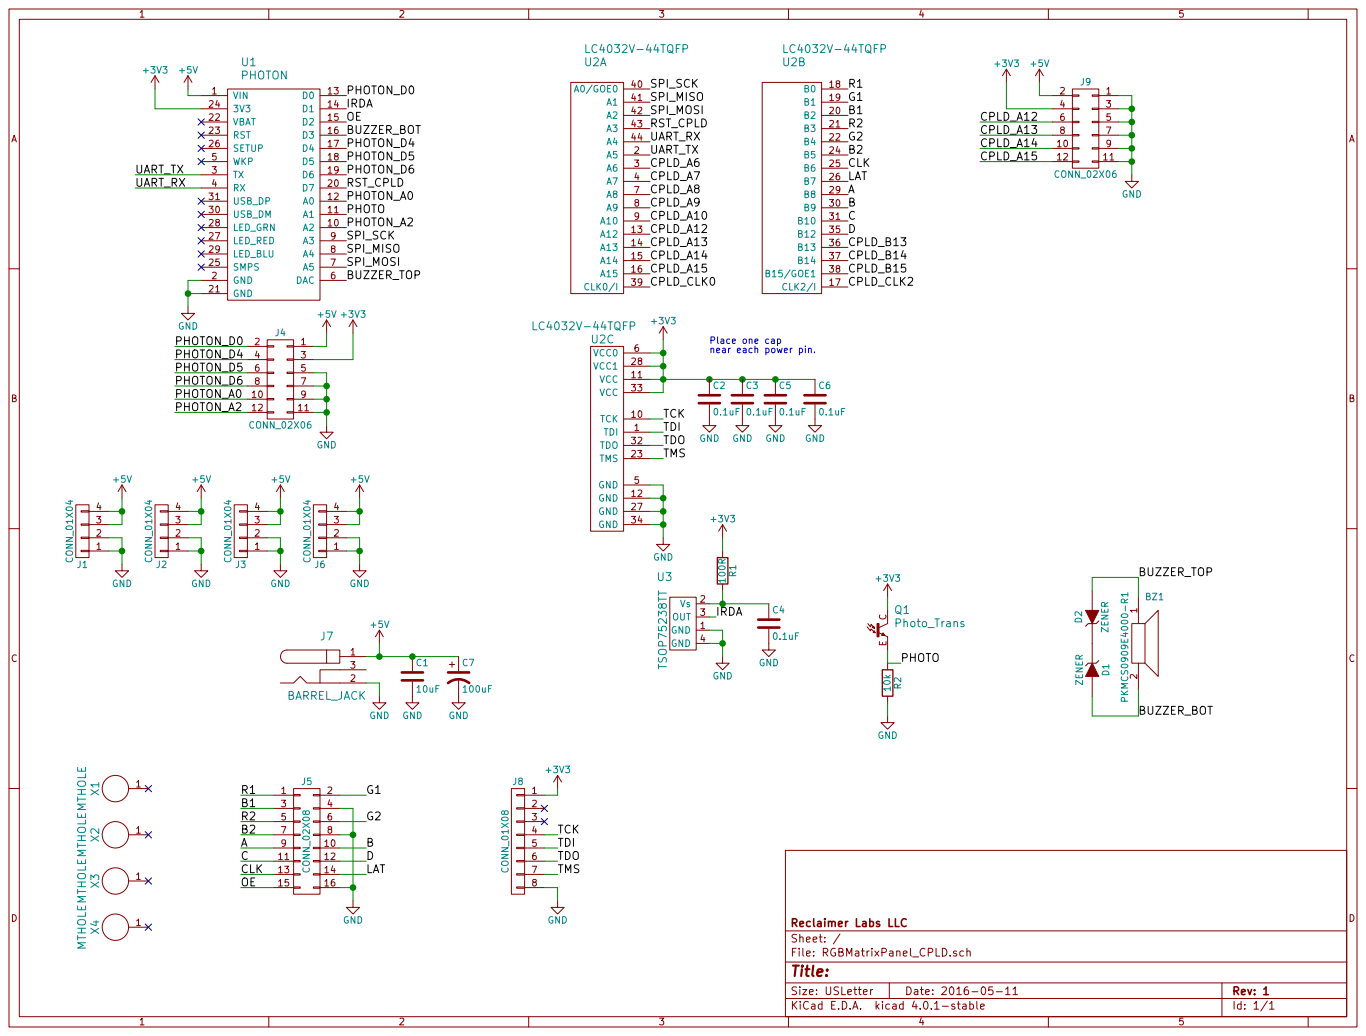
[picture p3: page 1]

10 | 9
12 | 11

File: RGBMatrixPanel_CPLD.sch Sheet: / Reclaimer Labs LLC

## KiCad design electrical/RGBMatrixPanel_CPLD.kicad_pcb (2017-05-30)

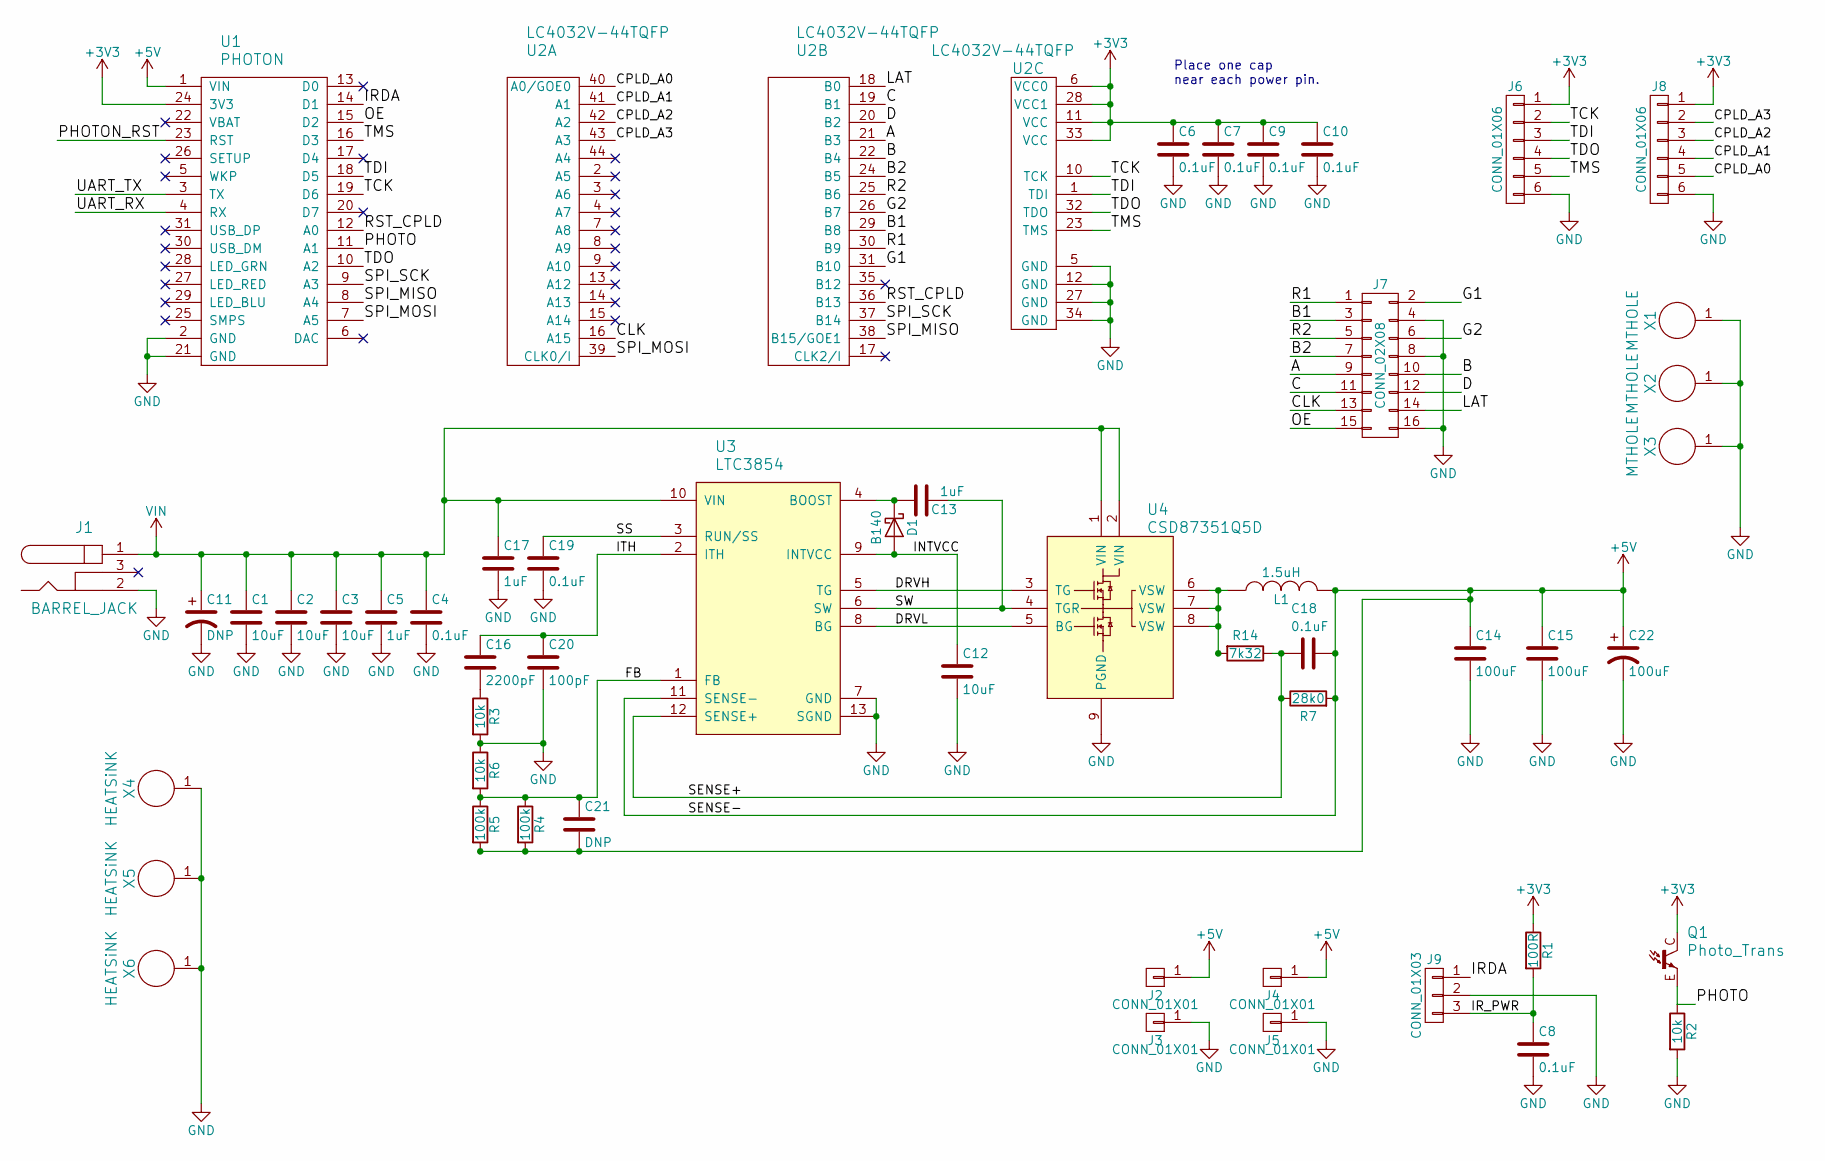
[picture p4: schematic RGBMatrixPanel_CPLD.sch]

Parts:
C1, C2, C3: 10uF; C_1206; Manufacturer Part Number CL31A106MBHNNNE
C4, C6, C7, C8, C9, C10, C18, C19: 0.1uF; C_0603; MacroFab Part Number MF-CAP-0603-0.1uF
C5, C13, C17: 1uF; C_0603; MacroFab Part Number MF-CAP-0603-1uF
C11: DNP; CP_Tantalum_Case-D_EIA-7343-31_Reflow; Manufacturer Part Number TCNX476M035R0100
C12: 10uF; C_0805; Manufacturer Part Number TMK212BBJ106KG-T
C14, C15: 100uF; C_1210; Manufacturer Part Number GRM32ER61A107ME20L
C16: 2200pF; C_0603; Manufacturer Part Number CL10B222KB8SFNC
C20: 100pF; C_0603; Manufacturer Part Number CL10C101JB8NCNC
C21: DNP; C_0603; MacroFab Part Number MF-CAP-0603-0.1uF
C22: 100uF; CP_Tantalum_Case-D_EIA-7343-31_Reflow; Manufacturer Part Number 593D227X0010E2TE3
D1: B140; D_SMA_Standard; MacroFab Part Number MF-DIO-SMA-B140
J1: BARREL_JACK; BARREL_JACK_PJ_202AH_Slots; Manufacturer Part Number PJ-202AH
J2, J3, J4, J5: CONN_01X01; 3547; Manufacturer Part Number 3547
J6, J8: CONN_01X06; Socket_Strip_Straight_1x06
J7: CONN_02X08; HEADER_THRU_02x08_POL; Manufacturer Part Number SFH11-PBPC-D08-ST-BK
J9: CONN_01X03; Socket_Strip_Straight_1x03
L1: 1.5uH; SRR1270; Manufacturer Part Number SRP1270-1R5M
Q1: Photo_Trans; Photo_Trans_ALS-PT19-315C; Manufacturer Part Number ALS-PT19-315C/L177/TR8
R1: 100R; C_0603; MacroFab Part Number MF-RES-0603-100
R2, R3, R6: 10k; C_0603; MacroFab Part Number MF-RES-0603-10K
R4, R5: 100k; C_0603; MacroFab Part Number MF-RES-0603-100K
R7: 28k0; C_0603; Manufacturer Part Number RC0603FR-0728KL
R14: 7k32; C_0603; Manufacturer Part Number RC0603FR-077K32L
U1: PHOTON
U2: LC4032V-44TQFP; QFP_44; Manufacturer Part Number LC4032V-75TN44C
U3: LTC3854; 12-MSE; Manufacturer Part Number LTC3854EMSE#PBF
U4: CSD87351Q5D; Manufacturer Part Number CSD87351Q5D
X1, X2, X3: MTHOLE; MountingHole_3.5mm_Pad_Via
X4, X5: HEATSiNK; 573100D00010G
X6: HEATSiNK; 573100D00010G; Manufacturer Part Number 573100D00010G

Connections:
+3V3: C6.1, C7.1, C9.1, C10.1, J6.1, J8.1, Q1.C, R1.1, U1.24 (3V3), U2.6 (VCC0), U2.11 (VCC), U2.28 (VCC1), U2.33 (VCC)
+5V: C14.1, C15.1, C18.1, C21.2, C22.1, J2.1, J4.1, L1.2, R4.2, R5.2, R7.2, U1.1 (VIN), U3.11 (SENSE-)
/A: J7.9, U2.21 (B3)
/B: J7.10, U2.22 (B4)
/B1: J7.3, U2.29 (B8)
/B2: J7.7, U2.24 (B5)
/C: J7.11, U2.19 (B1)
/CLK: J7.13, U2.16 (A15)
/CPLD_A0: J8.5, U2.40 (A0/GOE0)
/CPLD_A1: J8.4, U2.41 (A1)
/CPLD_A2: J8.3, U2.42 (A2)
/CPLD_A3: J8.2, U2.43 (A3)
/D: J7.12, U2.20 (B2)
/DRVH: U3.5 (TG), U4.3 (TG)
/DRVL: U3.8 (BG), U4.5 (BG)
/FB: C21.1, R4.1, R5.1, R6.2, U3.1 (FB)
/G1: J7.2, U2.31 (B10)
/G2: J7.6, U2.26 (B7)
/INTVCC: C12.1, D1.2 (A), U3.9 (INTVCC)
/IRDA: J9.1, U1.14 (D1)
/IR_PWR: C8.1, J9.3, R1.2
/ITH: C16.1, C20.1, U3.2 (ITH)
/LAT: J7.14, U2.18 (B0)
/OE: J7.15, U1.15 (D2)
/PHOTO: Q1.E, R2.1, U1.11 (A1)
/PHOTON_RST: U1.23 (RST)
/R1: J7.1, U2.30 (B9)
/R2: J7.5, U2.25 (B6)
/RST_CPLD: U1.12 (A0), U2.36 (B13)
/SENSE+: C18.2, R7.1, R14.1, U3.12 (SENSE+)
/SPI_MISO: U1.8 (A4), U2.38 (B15/GOE1)
/SPI_MOSI: U1.7 (A5), U2.39 (CLK0/I)
/SPI_SCK: U1.9 (A3), U2.37 (B14)
/SS: C19.1, U3.3 (RUN/SS)
/SW: C13.1, U3.6 (SW), U4.4 (TGR)
/TCK: J6.2, U1.19 (D6), U2.10 (TCK)
/TDI: J6.3, U1.18 (D5), U2.1 (TDI)
/TDO: J6.4, U1.10 (A2), U2.32 (TDO)
/TMS: J6.5, U1.16 (D3), U2.23 (TMS)
/UART_RX: U1.4 (RX)
/UART_TX: U1.3 (TX)
GND: C1.2, C2.2, C3.2, C4.2, C5.2, C6.2, C7.2, C8.2, C9.2, C10.2, C11.2, C12.2, C14.2, C15.2, C17.2, C19.2, C20.2, C22.2, J1.2, J3.1, J5.1, J6.6, J7.4, J7.8, J7.16, J8.6, J9.2, R2.2, R3.2, R6.1, U1.2 (GND), U1.21 (GND), U2.5 (GND), U2.12 (GND), U2.27 (GND), U2.34 (GND), U3.7 (GND), U3.13 (SGND), U4.9 (PGND), X1.1, X2.1, X3.1, X4.1, X5.1, X6.1
unnamed: C13.2, D1.1 (K), U3.4 (BOOST)
unnamed: C16.2, R3.1
unnamed: L1.1, R14.2, U4.6 (VSW), U4.7 (VSW), U4.8 (VSW)
VIN: C1.1, C2.1, C3.1, C4.1, C5.1, C11.1, C17.1, J1.1, U3.10 (VIN), U4.1 (VIN), U4.2 (VIN)

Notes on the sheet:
Place one cap near each power pin.

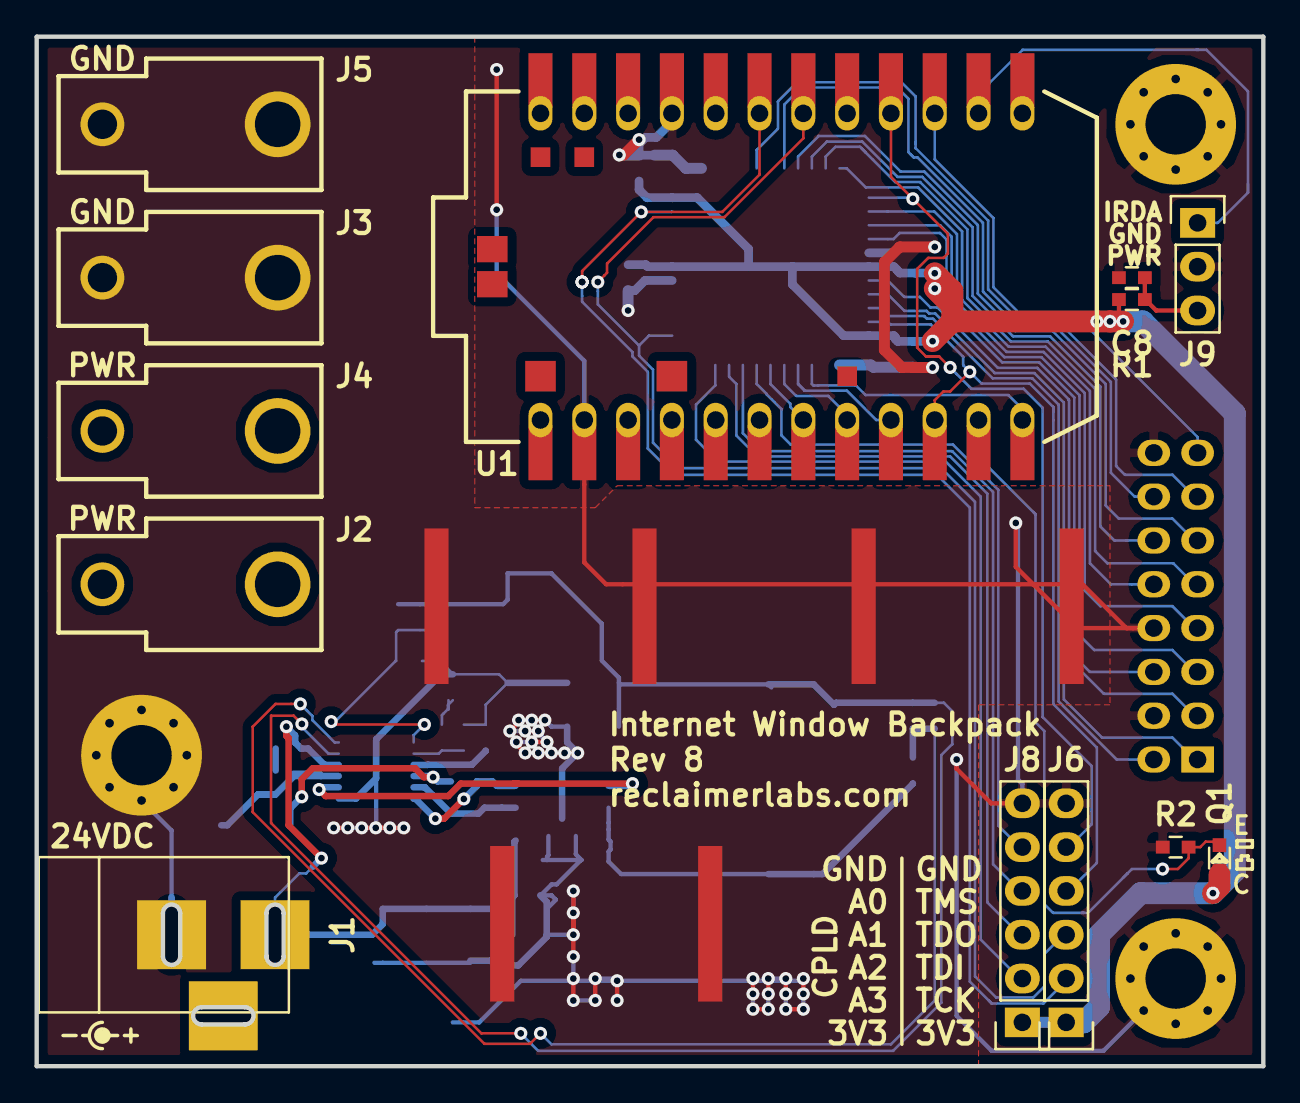
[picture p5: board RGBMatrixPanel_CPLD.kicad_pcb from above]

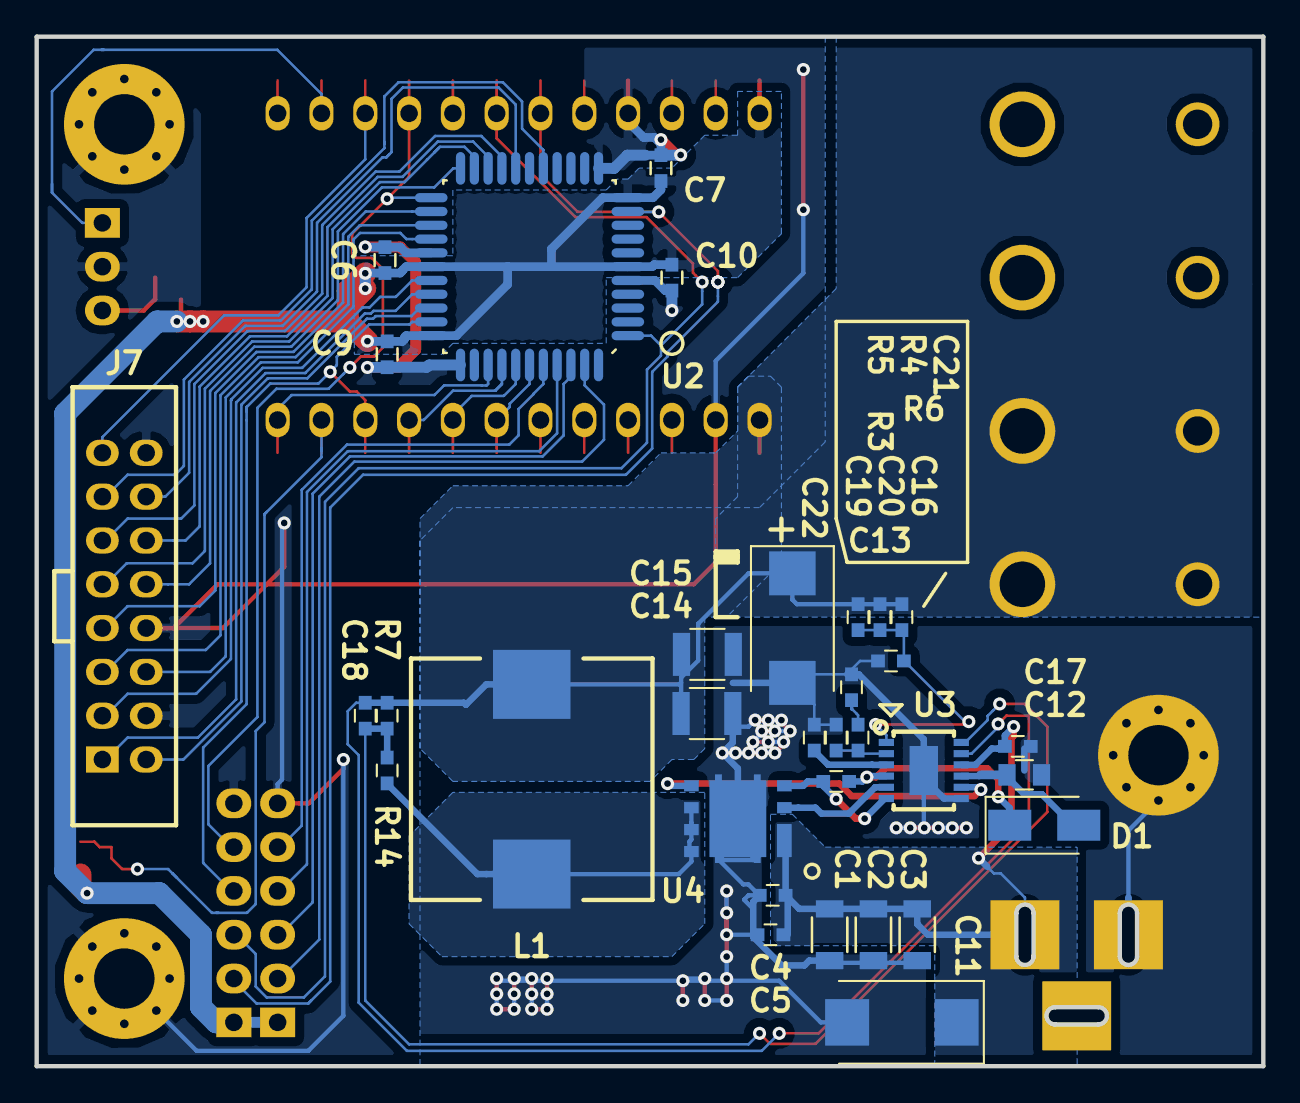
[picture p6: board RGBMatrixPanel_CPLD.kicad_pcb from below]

Board: 2 copper layers, 71.1 x 59.7 mm, 52 parts (33 on the bottom side), 43 nets.

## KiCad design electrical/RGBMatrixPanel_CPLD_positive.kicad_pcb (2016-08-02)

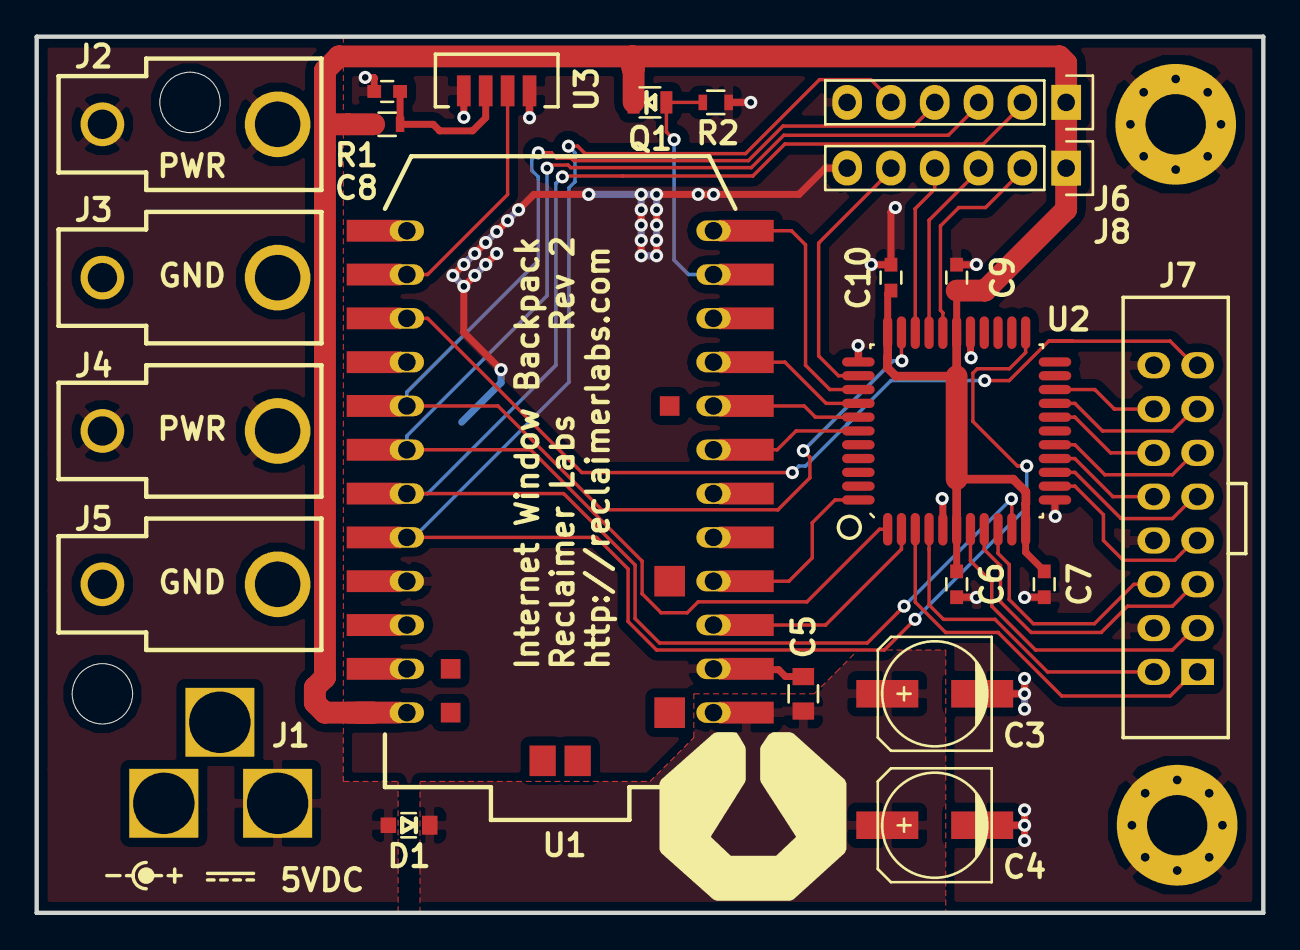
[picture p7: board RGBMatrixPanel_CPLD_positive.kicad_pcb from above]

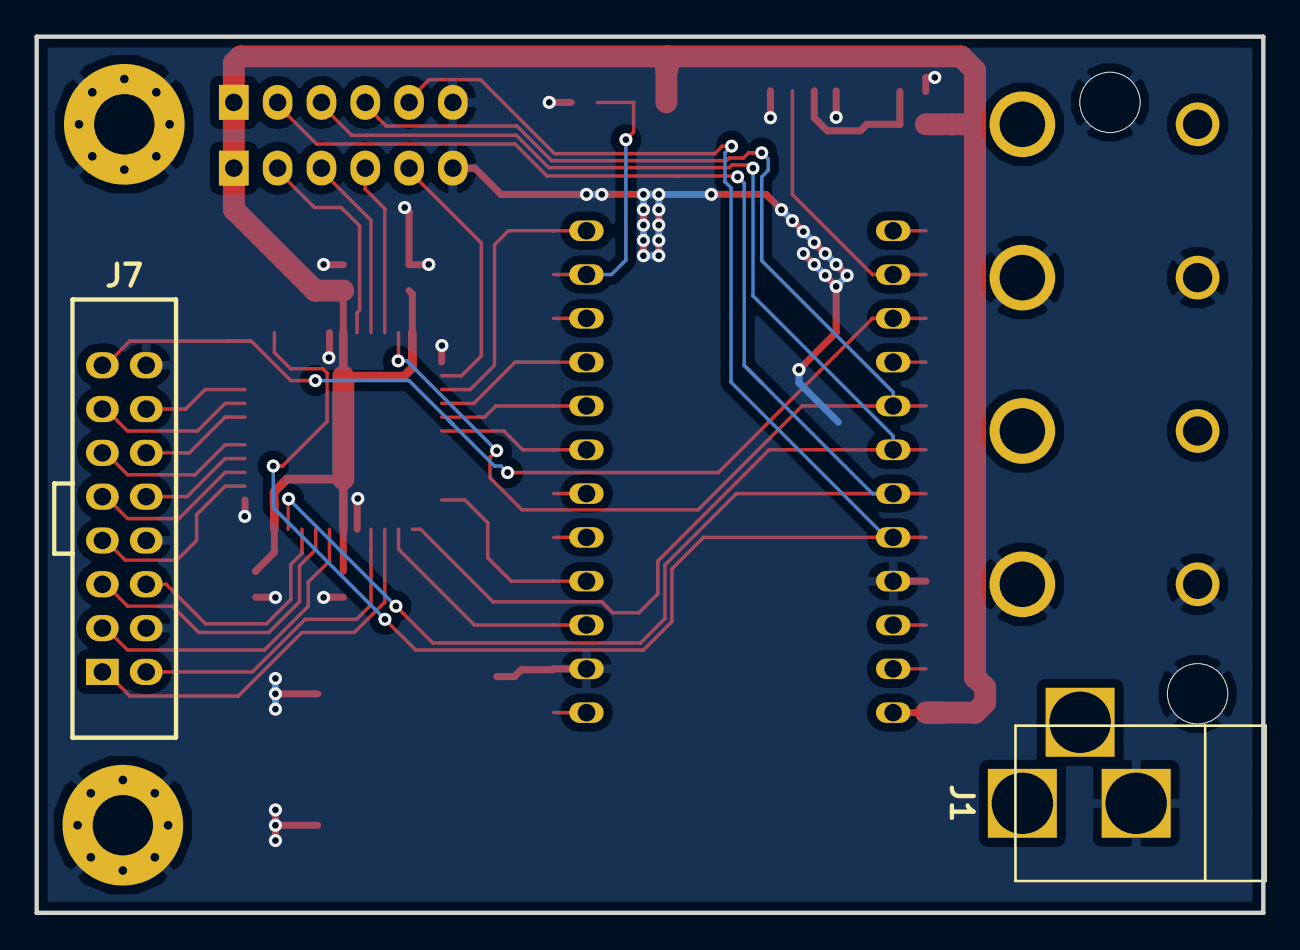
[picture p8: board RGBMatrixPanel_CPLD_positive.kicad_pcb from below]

Board: 2 copper layers, 71.1 x 50.8 mm, 27 parts (2 on the bottom side), 34 nets.

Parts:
C3, C4: 100uF; c_elec_6.3x5.7
C5: 10uF; C_0805
C6, C7, C8, C9, C10: 0.1uF; C_0603
D1: D_Schottky; SMini2-F5-B
J1: BARREL_JACK; BARREL_JACK_MPD_EJ508A
J2, J3, J4, J5: CONN_01X01; 3547
J6, J8: CONN_01X06; Socket_Strip_Straight_1x06
J7: CONN_02X08; HEADER_THRU_02x08_POL
Q1: Photo_Trans; Photo_Trans_0805
R1: 100R; R_0603
R2: 10k; R_0603
U1: PHOTON
U2: LC4032V-44TQFP; QFP_44
U3: TSOP75238TT
X1, X2: MTHOLE; MountingHole_3.5mm
X3, X4: MTHOLE; MountingHole_3.5mm_Pad_Via

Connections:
+3V3: C6.1, C7.1, C9.1, C10.1, J6.1, J8.1, Q1.C, R1.1, U1.24, U2.6, U2.11, U2.28, U2.33
+5V: D1.2, J1.1, J2.1, J4.1
+5VA: C3.1, C4.1, C5.1, D1.1, U1.1
/A: J7.9, U2.14
/B: J7.10, U2.15
/B1: J7.3, U2.7
/B2: J7.7, U2.13
/C: J7.11, U2.16
/CLK: J7.13, U2.19
/CPLD_B8: J8.2, U2.29
/CPLD_B9: J8.3, U2.30
/CPLD_B10: J8.4, U2.31
/CPLD_B12: J8.5, U2.35
/D: J7.12, U2.18
/G1: J7.2, U2.4
/G2: J7.6, U2.9
/IRDA: U1.14, U3.3
/LAT: J7.14, U2.20
/OE: J7.15, U1.15
/PHOTO: Q1.E, R2.1, U1.11
/R1: J7.1, U2.3
/R2: J7.5, U2.8
/RST_CPLD: U1.12, U2.36
/SPI_MISO: U1.8, U2.38
/SPI_MOSI: U1.7, U2.39
/SPI_SCK: U1.9, U2.37
/TCK: J6.2, U1.19, U2.10
/TDI: J6.3, U1.18, U2.1
/TDO: J6.4, U1.17, U2.32
/TMS: J6.5, U1.20, U2.23
/UART_RX: U1.4, U2.44
/UART_TX: U1.3, U2.2
GND: C3.2, C4.2, C5.2, C6.2, C7.2, C8.2, C9.2, C10.2, J1.2, J3.1, J5.1, J6.6, J7.4, J7.8, J7.16, J8.6, R2.2, U1.2, U1.21, U2.5, U2.12, U2.27, U2.34, U3.1, U3.4, X1.1, X2.1, X3.1, X4.1
unnamed: C8.1, R1.2, U3.2

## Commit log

2016-05-01 Initial Check-in
    Initial check-in of Rev 1 hardware.
    [RGBMatrixPanel_CPLD-B.Cu.gbl, RGBMatrixPanel_CPLD-B.Mask.gbs, RGBMatrixPanel_CPLD-B.Paste.gbp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]
2016-05-14 Debugging CPLD code
    Added timing diagrams for CPLD and low-level FW functions. Updated CPLD
    code to set a known reset state for latch_needed.
    [RGBMatrixPanel_CPLD.sch, rgbmatrixpanel_cpld_pin.csv]
2016-05-16 Simplified CPLD code
    Removed row_inc_needed register to simply verilog code. Also updated
    timing diagrams to match new hardware code.
    [rgbmatrixpanel_cpld_pin.csv]
2016-06-14 Updating documentation for Rev 1
    Updating documentation, zipped up gerbers, and created c files for
    programming CPLD from Photon
2016-08-02 Rev 2
    Updated board to Rev 2. Removed buzzer. Reduced number spare GPIOs.
    Added HW to program CPLD from Photon. Updated CPLD pinout in Lattice SW.
    [RGBMatrixPanel_CPLD-B.Cu.gbl, RGBMatrixPanel_CPLD-B.Mask.gbs, RGBMatrixPanel_CPLD-B.Paste.gbp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]
2016-10-19 Rev 3
    Updates include new board outline to accomendate mounting to sheet metal
    frame
    [RGBMatrixPanel_CPLD-B.Cu.gbl, RGBMatrixPanel_CPLD-B.Mask.gbs, RGBMatrixPanel_CPLD-B.Paste.gbp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]
2016-12-24 moved mounting hole
    Moved mounting hole to better align with the sheet metal frame
    [RGBMatrixPanel_CPLD-B.Cu.gbl, RGBMatrixPanel_CPLD-B.Mask.gbs, RGBMatrixPanel_CPLD-B.Paste.gbp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]
2017-02-14 Rev 5
    [RGBMatrixPanel_CPLD-B.Cu.gbl, RGBMatrixPanel_CPLD-B.Mask.gbs, RGBMatrixPanel_CPLD-B.Paste.gbp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]
2017-05-30 Added buck converter
    Added an on-board 24V to 5V buck converter to lower the current going
    through the connector to a safe level. Now the magic smoke stays safely
    contained.
    [RGBMatrixPanel_CPLD-B.Cu.gbl, RGBMatrixPanel_CPLD-B.Mask.gbs, RGBMatrixPanel_CPLD-B.Paste.gbp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]
